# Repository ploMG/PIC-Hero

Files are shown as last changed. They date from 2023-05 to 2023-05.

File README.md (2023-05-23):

# PIC Hero

##  General Info

This project allows the user to select songs and play them off a PIC16F1829. A selection screen is displayed by a 2x16 LCD through I2C that lets users choose which song they would like to play using an analog stick component. After a song is selected, the user will be able to play the notes of the song using the touch sensors on the PIC board. The notes of the song will be highlighted on an 8x8 dot matrix through SPI, where the lit LEDs on the dot matrix signify when to press certain notes. Simultaneously, songs are loaded into a DFPlayer Mini connected to an Arduino Nano 33 BLE Sense that communicates with the PIC microcontroller through UART, which will play the user-selected audio on a connected speaker component. When the song is over, the LCD will display the user's score.

## Setup

### PIC

The source file main.c can be written to the PIC through snap and is found in the maingame.X project folder.
This project was done using MPLAB X IDE v5.35 and XC8 v1.45 compiler, which can be downloaded from [Microchip](https://www.microchip.com/en-us/tools-resources/archives/mplab-ecosystem). 

### Arduino

The source file has three songs charted:

* (Easy) Foghat - Slow Ride
* (Medium) Foo Fighters - Everlong
* (Hard) Gojira - The Heaviest Matter of the Universe

The mp3 files of these songs were uploaded to a microSD and inserted into the DFPlayer. More info is available on the official [DFRobot page](https://wiki.dfrobot.com/DFPlayer_Mini_SKU_DFR0299).

The script to write to the Arduino is found in the arduino-DF folder. DFRobotDFPlayerMini library is required.

### (Optional) Case

CAD files to 3D print a holding case for the external components are available in the case folder.

## Samples

https://github.com/ploMG/PIC-Hero/assets/128610413/27b00fba-717c-41e0-9f21-f9e96394e969

> The Heaviest Matter of the Universe (no case)

###  



> EE 3463 Demo Day, April 20th, 2023

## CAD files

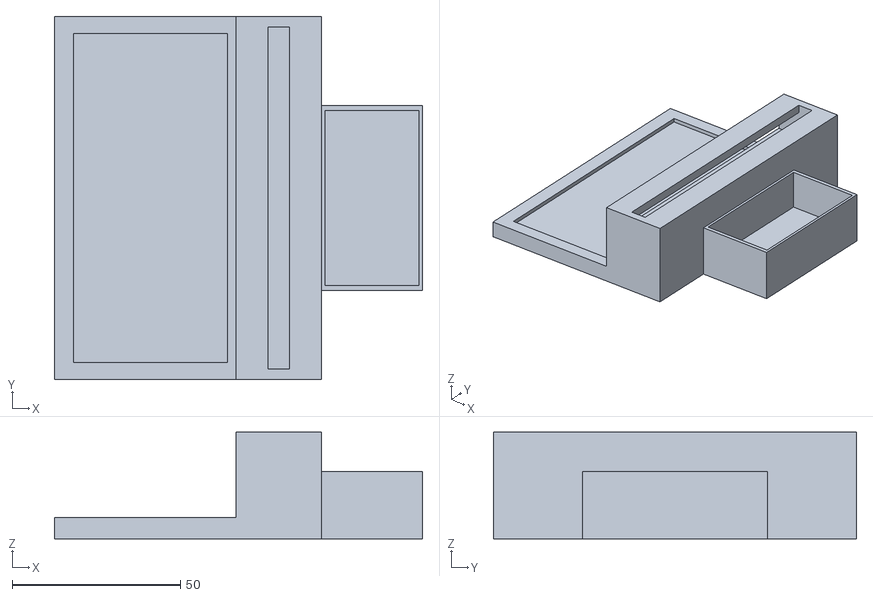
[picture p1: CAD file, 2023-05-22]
case/PICMicrocontrollerCaseV3.stl
109.4 x 107.9 x 31.8

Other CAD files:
maingame.X/dist/default/production/maingame.X.production.obj
case/PICHero Case.ipt

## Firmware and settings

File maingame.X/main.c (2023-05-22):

// Michael Gomez, Ranbir Singh, Angel Genao
// Dr. Morton, Microcomputer Systems I, Spring 2023

/* PIC HERO */

#include <xc.h>
#include <math.h>
#include <stdint.h>
#include <stdio.h>
#include <stdlib.h>
#include  "header/i2c.h"
#include  "header/i2c_LCD.h"


// PIC16F1829 Configuration Bit Settings
// 'C' source line config statements

// CONFIG1
#pragma config FOSC = INTOSC    // Oscillator Selection (INTOSC oscillator: I/O function on CLKIN pin)
#pragma config WDTE = OFF       // Watchdog Timer Enable (WDT disabled)
#pragma config PWRTE = OFF      // Power-up Timer Enable (PWRT disabled)
#pragma config MCLRE = ON       // MCLR Pin Function Select (MCLR/VPP pin function is MCLR)
#pragma config CP = OFF         // Flash Program Memory Code Protection (Program memory code protection is disabled)
#pragma config CPD = OFF        // Data Memory Code Protection (Data memory code protection is disabled)
#pragma config BOREN = ON       // Brown-out Reset Enable (Brown-out Reset enabled)
#pragma config CLKOUTEN = OFF   // Clock Out Enable (CLKOUT function is disabled. I/O or oscillator function on the CLKOUT pin)
#pragma config IESO = OFF       // Internal/External Switchover (Internal/External Switchover mode is disabled)
#pragma config FCMEN = OFF      // Fail-Safe Clock Monitor Enable (Fail-Safe Clock Monitor is disabled)

// CONFIG2
#pragma config WRT = OFF        // Flash Memory Self-Write Protection (Write protection off)
#pragma config PLLEN = OFF      // PLL Enable (4x PLL disabled)
#pragma config STVREN = ON      // Stack Overflow/Underflow Reset Enable (Stack Overflow or Underflow will cause a Reset)
#pragma config BORV = LO        // Brown-out Reset Voltage Selection (Brown-out Reset Voltage (Vbor), low trip point selected.)
#pragma config LVP = ON        // Low-Voltage Programming Enable (High-voltage on MCLR/VPP must be used for programming)

// UART/I2C Config
#define I2C_SLAVE 0x27	/* was 1E Channel of i2c slave depends on soldering on back of board*/
#define BAUD 9600  
#define FOSC 4000000L  
#define DIVIDER ((int)(FOSC/(16UL * BAUD) -1)) // Should be 25 for 9600/4MhZ  
#define NINE_BITS 0  
#define SPEED 0x4  
#define RX_PIN TRISC5  
#define TX_PIN TRISC4
#define _XTAL_FREQ 4000000.0    /*for 4mhz*/

// Define pins for 8x8
#define DIN LATCbits.LATC6
#define CS LATCbits.LATC2
#define CLK LATCbits.LATC3


// Prototypes
void I2C_LCD_Command(unsigned char,unsigned char);
void I2C_LCD_SWrite(unsigned char,unsigned char *, char);
void I2C_LCD_Init(unsigned char);
void I2C_LCD_Pos(unsigned char,unsigned char);
unsigned char I2C_LCD_Busy(unsigned char);
void pinConfig(void);  
void setup_comms(void);  
void putch(unsigned char);  
unsigned char getch(void);  
unsigned char getche(void);
void init8x8(void);
void SPI_Write(uint8_t data);
void MAX7219_Write(uint8_t reg, uint8_t data);
void display(const uint8_t *data);
void timer_config(void);
void clockAndpin_config(void);


//Global variables
int Touch[4];
int indx = 0; 
int Threshold = 0x15ce;     /*touchbutton sensitivity*/
int score = 0;
int push = 4;


void main(void) {

    pinConfig();  
  
    setup_comms(); // set up the USART - settings defined in usart.h  
    
    /*TouchPad Setup*/  
    CPSCON0 = 0x8C;   //Set up Touch sensing module control reg 0
    
    Touch[0] = 0x04;// RC0 pad CPS4
    Touch[1] = 0x05;// RC1 pad CPS5
    Touch[2] = 0x09;// RC7 pad CPS9
    Touch[3] = 0x03;// RA4 pad CPS3
    
    /*Clock and Pin Configuration*/
    clockAndpin_config();      //Configures clock and pins, enables timers
    timer_config();

    //Variables
	unsigned char  Sout[16];
	unsigned char * Sptr;
    int z;
    int song;
    int write;
    unsigned int shift;
	Sptr = Sout;

    //Clock and Pin Configs
    // Get set up for A2D  
    ADCON1 = 0xC0; //Right justify and Fosc/4 and Vss and Vdd references
	OSCCON  = 0x6A; /* b6..4 = 1101 = 4MHz */
    TRISA = 0x00; //0b00000000 TRIS is like mode( i.e. output or input)
    PORTA = 0x00; //0b00000000 PORT is like status (i.e. on or off)
    TRISB = 0x07;
    ANSELB = 0x00;
    LATA5 = 1;  //Green
    LATA2 = 1;  //Blue
    LATC6 = 1;  //Red  

	/*  ********************************I2C**************************** */
	/*  Note the I2C write to LCD uses the 8 bits of the PCF8574 chip to control the LCD  */
	/*  Connected High 4 bits are High 4 data for LCD (use in 4 bit mode)  the other 4 are     */
	/*  bit3=turn on /off bk light  bit 2= E line writes on Hi 2 Lo transition, reads Lo to Hi */
	/*  bit 2=Read write set  to 0 for write   bit 0=RS  command=0 Data=1      */
	/*  ********************************I2C**************************** */
    
    // SDA -> RB4
    // SCL -> RB6
	i2c_Init();				// Start I2C as Master 100KH
	I2C_LCD_Init(I2C_SLAVE); //pass I2C_SLAVE to the init function to create an instance
	


	//Selection Screen

    while(1){

    I2C_LCD_Command(I2C_SLAVE, 0x01);
    I2C_LCD_Pos(I2C_SLAVE,0x00);
    sprintf(Sout, " Click to Start ");
    I2C_LCD_SWrite(I2C_SLAVE, Sout, 16);

    I2C_LCD_Pos(I2C_SLAVE,0x40);  
    sprintf(Sout, "    PIC Hero");
    I2C_LCD_SWrite(I2C_SLAVE, Sout, 12);

    while(RB7 == 1){
        __delay_ms(10);   
    }
    
    __delay_ms(300);
        
    I2C_LCD_Command(I2C_SLAVE, 0x01);
    I2C_LCD_Pos(I2C_SLAVE,0x00);
    sprintf(Sout, " Easy Med Hard ");
    I2C_LCD_SWrite(I2C_SLAVE, Sout, 15);
    
    I2C_LCD_Pos(I2C_SLAVE,0x40);  
    sprintf(Sout, " ----");
    I2C_LCD_SWrite(I2C_SLAVE, Sout, 5);
    
    song = 1;
    
    do{
           /*Y value read*/
       ADCON0 = 0x1D; // set up for the analog stick directional input channel = AN7
       __delay_ms(10); //Allow cap to recharge  
       ADGO = 1; // initiate conversion on the selected channel  
       while(ADGO)continue;  
       shift = ((ADRESH<<8)+(ADRESL)); //Store 10 bits into Pval, 8 + 2
       
       if (shift < 250){
           if (song == 1)
           {
                I2C_LCD_Command(I2C_SLAVE, 0x01);
                I2C_LCD_Pos(I2C_SLAVE,0x00);
                sprintf(Sout, " Easy Med Hard ");
                I2C_LCD_SWrite(I2C_SLAVE, Sout, 15);

                I2C_LCD_Pos(I2C_SLAVE,0x40);
                sprintf(Sout, "      ---");
                I2C_LCD_SWrite(I2C_SLAVE, Sout, 9);   
                __delay_ms(500);
                
                song = 2;
           }

            else if (song == 2)
           {
                I2C_LCD_Command(I2C_SLAVE, 0x01);
                I2C_LCD_Pos(I2C_SLAVE,0x00);
                sprintf(Sout, " Easy Med Hard ");
                I2C_LCD_SWrite(I2C_SLAVE, Sout, 15);

                I2C_LCD_Pos(I2C_SLAVE,0x40);
                sprintf(Sout, "          ----");
                I2C_LCD_SWrite(I2C_SLAVE, Sout, 14);
                __delay_ms(500);
                
                song = 3;
           }
       }
       
       else if (shift > 750){
            if (song == 2)
           {
                I2C_LCD_Command(I2C_SLAVE, 0x01);
                I2C_LCD_Pos(I2C_SLAVE,0x00);
                sprintf(Sout, " Easy Med Hard ");
                I2C_LCD_SWrite(I2C_SLAVE, Sout, 15);

                I2C_LCD_Pos(I2C_SLAVE,0x40);
                sprintf(Sout, " ----");
                I2C_LCD_SWrite(I2C_SLAVE, Sout, 5);
                __delay_ms(500);
                
                song = 1;
           }

            else if (song == 3)
           {
                I2C_LCD_Command(I2C_SLAVE, 0x01);
                I2C_LCD_Pos(I2C_SLAVE,0x00);
                sprintf(Sout, " Easy Med Hard ");
                I2C_LCD_SWrite(I2C_SLAVE, Sout, 15);

                I2C_LCD_Pos(I2C_SLAVE,0x40);
                sprintf(Sout, "      ---");
                I2C_LCD_SWrite(I2C_SLAVE, Sout, 9);
                __delay_ms(500);
                
                song = 2;
           }
       }
       
    } while (RB7 == 1);
    
    I2C_LCD_Command(I2C_SLAVE, 0x01);

    I2C_LCD_Pos(I2C_SLAVE,0x00);
    sprintf(Sout, "     Ready?");
    I2C_LCD_SWrite(I2C_SLAVE, Sout, 11);
        
    __delay_ms(2000);
                
    I2C_LCD_Command(I2C_SLAVE, 0x01);
        
    I2C_LCD_Pos(I2C_SLAVE,0x40);
    sprintf(Sout, "      Go!");
    I2C_LCD_SWrite(I2C_SLAVE, Sout, 9);
    
    //Set ISR
    TMR0IE = 1;
    GIE = 1;
    
        //Begin note display on 8x8 matrix
    
    if (song == 1) slowride();
    else if (song == 2) everlong();
    else if (song == 3) heaviest();
    
    TMR0IE = 0;
    GIE = 0;
    
        //Score screen

    I2C_LCD_Command(I2C_SLAVE, 0x01);
    
    I2C_LCD_Pos(I2C_SLAVE,0x00);
    sprintf(Sout, "Score: %d", score);
    
    if (score >= 10000){
        write = 12;
    }
    else if (score >= 1000){
        write = 11;
    }
    else if (score >= 100){
        write = 10;
    }
    else if (score >= 10){
        write = 9;
    }
    else write = 8;
    
    I2C_LCD_SWrite(I2C_SLAVE, Sout, write);
    
    while(RB7 == 1){
        __delay_ms(10);   
    }
    
    __delay_ms(300);

    }
}


void setup_comms(void)  {  
RX_PIN = 1;  
TX_PIN = 1;  
SPBRG = DIVIDER;  
RCSTA = (NINE_BITS | 0x90);  
TXSTA = (SPEED | NINE_BITS | 0x20);  
TXEN = 1;  
SYNC = 0;  
SPEN = 1;  
BRGH = 1;  
  }  

void putch(unsigned char byte)  {  
/* output one byte */  
while(!TXIF) /* set when register is empty */  
continue;  
TXREG = byte;  
  }  

unsigned char getch()  {  
/* retrieve one byte */  
while(!RCIF) /* set when register is not empty */  
continue;  
return RCREG;  
  }  

unsigned char getche(void)  {  
unsigned char c;  
putch(c = getch());  
return c;  
  }  
  
void pinConfig(void)  {  
 TXCKSEL = 1; // both bits in APFCON0 MUST BE 1 for 1829 0 for 1825  
 RXDTSEL = 1; /* makes RC4 & 5 TX & RX for USART (Allows ICSP)*/  
  }

void init8x8(void) {
    OSCCON = 0x68; // 4 MHz internal oscillator
    ANSELC = 0x00; // Set PORTC as digital
    TRISC = 0x00;  // Set PORTC as output
    DIN = 0;
    CS = 0;
    CLK = 0;
}

void SPI_Write(uint8_t data) {
    for (uint8_t i = 0; i < 8; i++) {
        CLK = 0;
        DIN = (data & 0x80) >> 7; // Send MSB
        data <<= 1;
        CLK = 1;
    }
}

void MAX7219_Write(uint8_t reg, uint8_t data) {
    CS = 0;
    SPI_Write(reg);
    SPI_Write(data);
    CS = 1;
}

void display(const uint8_t *data) {
    for (uint8_t i = 0; i < 8; i++) {
        MAX7219_Write(i + 1, data[i]);
    }
}


void greennote(){
    push = 0;
}

void rednote(){
    push = 1;
}

void yellownote(){
    push = 2;
}

void bluenote(){
    push = 3;
}

void emptynote(){
    push = 4;
}

void delay1(){
    __delay_ms(526); //slowride tempo
}

void delay2(){
    __delay_ms(127); //everlong tempo
}

void delay3(){
    __delay_ms(97);  //THMOTU tempo
}


void clockAndpin_config(){
    OSCCON      =	0X6A;  	//set up 4MHz for Fosc
    INTCON      =   0;      // purpose of disabling the interrupts.
    OPTION_REG  =   0XC5;  	// set up timer 0, and then timer 1
    T1CON    	=	0XC1;   //TMR 1 Enable
    T1GCON   	=  	0X81;   //81 is without toggle mode A1 is toggle mode
    TRISA   	= 	0X10;
    TRISC   	=	0XFF;
    PORTA   	= 	0;
    ANSELA  	=   0X10;
}

void timer_config(){
    TMR0    	=   0;
    TMR1H       =   0;
    TMR1L   	=   0;
    TMR1ON      =   1;
    TMR0IF  	=   0;      	//Clear the interrupt flag for Timer 1
    TMR0    	=   0;  
}

void interrupt get_Touch(void){     /*ISR - reads user input on touchbuttons*/
        
    if (TMR0IF != 1) RESET();
    
    CPSCON1 = Touch[indx];
    
    if(((TMR1H<<8)+TMR1L) < Threshold) {

    // ****HereCheck if correct pad pushed is equal to indx and add points
        if(indx == push){
            score +=10;        
        }
    }
    
    timer_config();
    indx +=1;

    if (indx > 3) indx = 0; //cycle indx from 0,1,2,3 and back to 0
    
}



/*Ctrl + Shift + Minus to fold code for easy viewing*/



// Notes for Song 1
const uint8_t green1_1[8] ={ 

    0b00100000,

    0b00000000,    

    0b00000000,

    0b00000000,

    0b00000000,

    0b00000000,

    0b00000000,

    0b00000000

};
const uint8_t green1_2[8] ={

    0b00000000,

    

    0b00100000,

    

    0b00000000,



    0b00000000,



    0b00000000,



    0b00000000,



    0b00000000,



    0b00000000

};
const uint8_t green1_3[8] ={

    0b00100000,

    

    0b00000000,

    

    0b00100000,



    0b00000000,



    0b00000000,



    0b00000000,



    0b00000000,



    0b00000000

};
const uint8_t green1[8] = {





    0b00000000,

    

    0b00100000,

    

    0b00000000,



    0b00100000,



    0b00000000,



    0b00000000,



    0b00000000,



    0b00000000



};
const uint8_t green2[8] = {



    0b00100000,



    0b00000000,

    

    0b00100000,

    

    0b00000000,



    0b00100000,



    0b00000000,



    0b00000000,



    0b00000000





};
const uint8_t green3[8] = {



    

    0b00000000,



    0b00100000,



    0b00000000,

    

    0b00100000,

    

    0b00000000,



    0b00100000,



    0b00000000,



    0b00000000



};//delay yellow
const uint8_t green4[8] = {



    0b00010000,

    

    0b00000000,



    0b00100000,



    0b00000000,

    

    0b00100000,

    

    0b00000000,



    0b00100000,



    0b00000000



};
const uint8_t green5[8] = {



    0b00001000,



    0b00010000,

    

    0b00000000,



    0b00100000,



    0b00000000,

    

    0b00100000,

    

    0b00000000,



    0b00100000



};
const uint8_t green6[8] = {



    0b00100000,



    0b00001000,



    0b00010000,

    

    0b00000000,



    0b00100000,



    0b00000000,

    

    0b00100000,

    

    0b00000000

};
const uint8_t green7[8] = {



    0b00000000,



    0b00100000,



    0b00001000,



    0b00010000,

    

    0b00000000,



    0b00100000,



    0b00000000,

    

    0b00100000

            

};// 2nd delay yellow
const uint8_t green8[8] = {



    0b00100000,

    

    0b00000000,



    0b00100000,



    0b00001000,



    0b00010000,

    

    0b00000000,



    0b00100000,



    0b00000000

};
const uint8_t green9[8] = {



    0b00000000,

    

    0b00100000,

    

    0b00000000,



    0b00100000,



    0b00001000,



    0b00010000,

    

    0b00000000,



    0b00100000

};
const uint8_t green10[8] = {



    0b00100000,



    0b00000000,

    

    0b00100000,

    

    0b00000000,



    0b00100000,



    0b00001000,



    0b00010000,

    

    0b00000000

}; // yellow
const uint8_t green11[8] = {



    0b00000100,



    0b00100000,



    0b00000000,

    

    0b00100000,

    

    0b00000000,



    0b00100000,



    0b00001000,



    0b00010000

};
const uint8_t green12[8] = {



    0b00000100,

    

    0b00000100,



    0b00100000,



    0b00000000,

    

    0b00100000,

    

    0b00000000,



    0b00100000,



    0b00001000

};
const uint8_t green13[8] = {



    0b00000100,



    0b00000100,

    

    0b00000100,



    0b00100000,



    0b00000000,

    

    0b00100000,

    

    0b00000000,



    0b00100000

}; //yellow
const uint8_t green14[8] = {





    0b00100000,



    0b00000100,



    0b00000100,

    

    0b00000100,



    0b00100000,



    0b00000000,

    

    0b00100000,

    

    0b00000000

};
const uint8_t green15[8] = {



    0b00000000,



    0b00100000,



    0b00000100,



    0b00000100,

    

    0b00000100,



    0b00100000,



    0b00000000,

    

    0b00100000

};
const uint8_t green16[8] = {



    0b00100000,

    

    0b00000000,



    0b00100000,



    0b00000100,



    0b00000100,

    

    0b00000100,



    0b00100000,



    0b00000000

};
const uint8_t green17[8] = {



    0b00000000,

    

    0b00100000,

    

    0b00000000,



    0b00100000,



    0b00000100,



    0b00000100,

    

    0b00000100,



    0b00100000

};
const uint8_t green18[8] = {



    0b00100000,



    0b00000000,

    

    0b00100000,

    

    0b00000000,



    0b00100000,



    0b00000100,



    0b00000100,

    

    0b00000100

};
const uint8_t green19[8] = {



    0b00000000,



    0b00100000,



    0b00000000,

    

    0b00100000,

    

    0b00000000,



    0b00100000,



    0b00000100,



    0b00000100

};
const uint8_t green20[8] = {



    0b00010000,

    

    0b00000000,



    0b00100000,



    0b00000000,

    

    0b00100000,

    

    0b00000000,



    0b00100000,



    0b00000100

};
const uint8_t green21[8] = {



    0b00001000,



    0b00010000,

    

    0b00000000,



    0b00100000,



    0b00000000,

    

    0b00100000,

    

    0b00000000,



    0b00100000

};
const uint8_t green22[8] = {



    0b00100000,



    0b00001000,



    0b00010000,

    

    0b00000000,



    0b00100000,



    0b00000000,

    

    0b00100000,

    

    0b00000000

};
const uint8_t green23[8] = {



    0b00000000,



    0b00100000,



    0b00001000,



    0b00010000,

    

    0b00000000,



    0b00100000,



    0b00000000,

    

    0b00100000

};
const uint8_t green24[8] = {



    0b00100000,

    

    0b00000000,



    0b00100000,



    0b00001000,



    0b00010000,

    

    0b00000000,



    0b00100000,



    0b00000000

};
const uint8_t green25[8] = {



    0b00000000,

    

    0b00100000,

    

    0b00000000,



    0b00100000,



    0b00001000,



    0b00010000,

    

    0b00000000,



    0b00100000

};
const uint8_t green26[8] = {



    0b00100000,



    0b00000000,

    

    0b00100000,

    

    0b00000000,



    0b00100000,



    0b00001000,



    0b00010000,

    

    0b00000000

};
const uint8_t green27[8] = {



    0b00000100,



    0b00100000,



    0b00000000,

    

    0b00100000,

    

    0b00000000,



    0b00100000,



    0b00001000,



    0b00010000

};
const uint8_t green28[8] = {



    0b00000100,

    

    0b00000100,



    0b00100000,



    0b00000000,

    

    0b00100000,

    

    0b00000000,



    0b00100000,



    0b00001000

};
const uint8_t green29[8] = {



    0b00000100, //36



    0b00000100,

    

    0b00000100,



    0b00100000,



    0b00000000,

    

    0b00100000,

    

    0b00000000,



    0b00100000

};
const uint8_t green30[8] = {



    0b00100000,

    

    0b00000100, //36



    0b00000100,

    

    0b00000100,



    0b00100000,



    0b00000000,

    

    0b00100000,

    

    0b00000000

};
const uint8_t green31[8] = {





    0b00000000,



    0b00100000,



    0b00000100, //36



    0b00000100,

    

    0b00000100,



    0b00100000,



    0b00000000,

    

    0b00100000

};
const uint8_t green32[8] = {



    0b00001000,

    

    0b00000000,



    0b00100000,



    0b00000100, //36



    0b00000100,

    

    0b00000100,



    0b00100000,



    0b00000000

};
const uint8_t green33[8] = {



    0b00010000,

    

    0b00001000,

    

    0b00000000,



    0b00100000,



    0b00000100, //36



    0b00000100,

    

    0b00000100,



    0b00100000 //33

};
const uint8_t green34[8] = {



    0b00100000,



    0b00010000,

    

    0b00001000,

    

    0b00000000,



    0b00100000,



    0b00000100, //36



    0b00000100,

    

    0b00000100

};
const uint8_t green35[8] = {



    0b00000000,



    0b00100000,



    0b00010000,

    

    0b00001000,

    

    0b00000000,



    0b00100000,



    0b00000100, //36



    0b00000100

};
const uint8_t green36[8] = {



    0b00100000,



    0b00000000,



    0b00100000,



    0b00010000,

    

    0b00001000,

    

    0b00000000,



    0b00100000,



    0b00000100 //36

};
const uint8_t green37[8] = {



    0b00000000,



    0b00100000,



    0b00000000,



    0b00100000,



    0b00010000,

    

    0b00001000,

    

    0b00000000,



    0b00100000

};
const uint8_t green38[8] = {



    0b00100000,



    0b00000000,



    0b00100000,



    0b00000000,



    0b00100000,



    0b00010000,

    

    0b00001000,

    

    0b00000000

};
const uint8_t green39[8] = {



    0b00000000,



    0b00100000,



    0b00000000,



    0b00100000,



    0b00000000,



    0b00100000,



    0b00010000,

    

    0b00001000

};
const uint8_t green40[8] = {



    0b00001000,

    

    0b00000000,



    0b00100000,



    0b00000000,



    0b00100000,



    0b00000000,



    0b00100000,



    0b00010000 //40

};
const uint8_t green41[8] = {



    0b00010000,

    

    0b00001000,

    

    0b00000000,



    0b00100000,



    0b00000000,



    0b00100000,



    0b00000000,



    0b00100000

};
const uint8_t green42[8] = {





    0b00100000,



    0b00010000,

    

    0b00001000,

    

    0b00000000,



    0b00100000,



    0b00000000,



    0b00100000,



    0b00000000

};
const uint8_t green43[8] = {



    0b00000000,



    0b00100000,



    0b00010000,

    

    0b00001000,

    

    0b00000000,



    0b00100000,



    0b00000000,



    0b00100000

};
const uint8_t green44[8] = {



    0b00100000,



    0b00000000,//50



    0b00100000,



    0b00010000,

    

    0b00001000,

    

    0b00000000,



    0b00100000,



    0b00000000 //44



};
const uint8_t green45[8] = {



    0b00000000,



    0b00100000,



    0b00000000,//50



    0b00100000,



    0b00010000,

    

    0b00001000,

    

    0b00000000,



    0b00100000



};
const uint8_t green46[8] = {



    0b00000000,



    0b00000000,



    0b00100000,



    0b00000000,//50



    0b00100000,



    0b00010000,

    

    0b00001000,

    

    0b00000000



};
const uint8_t green47[8] = {



    0b00000000,



    0b00000000,



    0b00000000,



    0b00100000,



    0b00000000,//50



    0b00100000,



    0b00010000,

    

    0b00001000



};
const uint8_t green48[8] = {



    0b00000000,

    

    0b00000000,



    0b00000000,



    0b00000000,



    0b00100000,



    0b00000000,//50



    0b00100000,



    0b00010000



};
const uint8_t green49[8] = {







    0b00000000,

    

    0b00000000,

    

    0b00000000,



    0b00000000,



    0b00000000,



    0b00100000,



    0b00000000,//50



    0b00100000



};
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

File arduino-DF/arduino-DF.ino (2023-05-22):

#include "Arduino.h"
#include "DFRobotDFPlayerMini.h"

UART DFSerial(digitalPinToPinName(11), digitalPinToPinName(10), NC, NC);  //11 is tx, 10 is rx
DFRobotDFPlayerMini myDFPlayer;

void setup()
{
  DFSerial.begin(9600);   // df player connection
  Serial1.begin(9600);    // UART PIC connection, 1 is tx and 2 is rx on Arduino Nano 33 BLE

  if (!myDFPlayer.begin(DFSerial)) {  //wait till df is online
    delay(100);
    while(true);
  }

  myDFPlayer.volume(20);  //Set volume from 0 to 30
}

void loop() {
  
  if (Serial1.available() > 0) {
    
    int song = Serial1.read();
    
    if (song >= '0' && song <= '9') {
      
      song -= '0';  // Convert ASCII to actual integer
      
      if (song == 1){
        myDFPlayer.play(2);  //Play Slow Ride
        delay(29000);
        myDFPlayer.pause();  //pause the mp3
        Serial1.end();   /*end serial communication*/
        Serial1.begin(9600);
      }
      else if (song == 2){
        myDFPlayer.play(3);  //Play Everlong
        delay(28000);
        myDFPlayer.pause();  //pause the mp3
        Serial1.end();   /*end serial communication*/
        Serial1.begin(9600);
      }
      else if (song == 3){
        myDFPlayer.play(1);  //Play Heaviest Matter
        delay(13750);
        myDFPlayer.pause();  //pause the mp3
        Serial1.end();   /*end serial communication*/
        Serial1.begin(9600);
      }
    }
  }
}

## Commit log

2023-05-22 Added game files
    [maingame.X.production.obj]
2023-05-22 Added 3D print files
    [PICHero Case.ipt, PICMicrocontrollerCaseV3.stl]
